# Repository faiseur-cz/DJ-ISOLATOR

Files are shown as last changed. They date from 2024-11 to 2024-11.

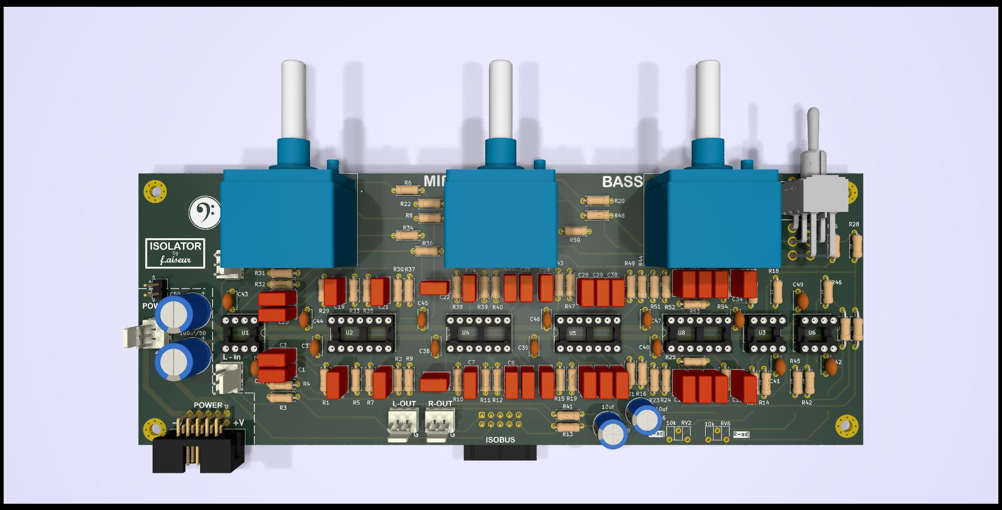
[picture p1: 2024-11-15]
ISOLATOR v002 top.jpg

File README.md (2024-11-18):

# DJ-ISOLATOR
Open-source project of a 3-band "dj isolator"

When i built my first Pathos rotary mixer, a clone of the infamous Bozak CMA-10-2DL, by australian engineer Miles Stevens-aka Fabric Astronaut-, I knew i needed an isolator... so i bought 3 PCBs, from different horizons... i payed a sh+t lot of money for them... and although they worked well, i thought they were not worth it... dont get me wrong! im not criticizing the products, they are all great and amazing, but i felt i could just make it myself, for less money...
Of course, i ended up paying way more... somehow the price of self satisfaction... I learned a lot - and hopefully you will too!

anyway, lets not loose the point!

I basically copied everything from the very generous ESP (Elliott Sound Products) website.. under project numbers :
- Project 09 : 3-Way Linkwitz Riley Crossover
- Project 153 : Frequency 'Isolator' Equaliser
And a lot of other tips from this great knowledge base.

It is a 24dB/oct filter, with frequencies set up at 310Hz and 3k1Hz. You can change those values up to your tastes, for this I can only advise you to fly on ROD ELLIOTT's WEBSITE!!
You can use high quality potentiometers RK27 or more standard ones (i like center detent in those spots).
Either Molex or IDC 10pins connectors are possible for In/Out and power.

https://sound-au.com
https://sound-au.com/project09.htm
https://sound-au.com/project153.htm

https://fabricastronautblog.wordpress.com/2019/06/27/bozak-cma-10-2dl-pt-1-begining/
https://fabricastronautblog.wordpress.com/2016/07/24/pathos-dj-mixer-pt-1/
https://fabricastronautblog.wordpress.com/2016/05/25/dj-isolator-v1-0/

ISOLATOR pcb

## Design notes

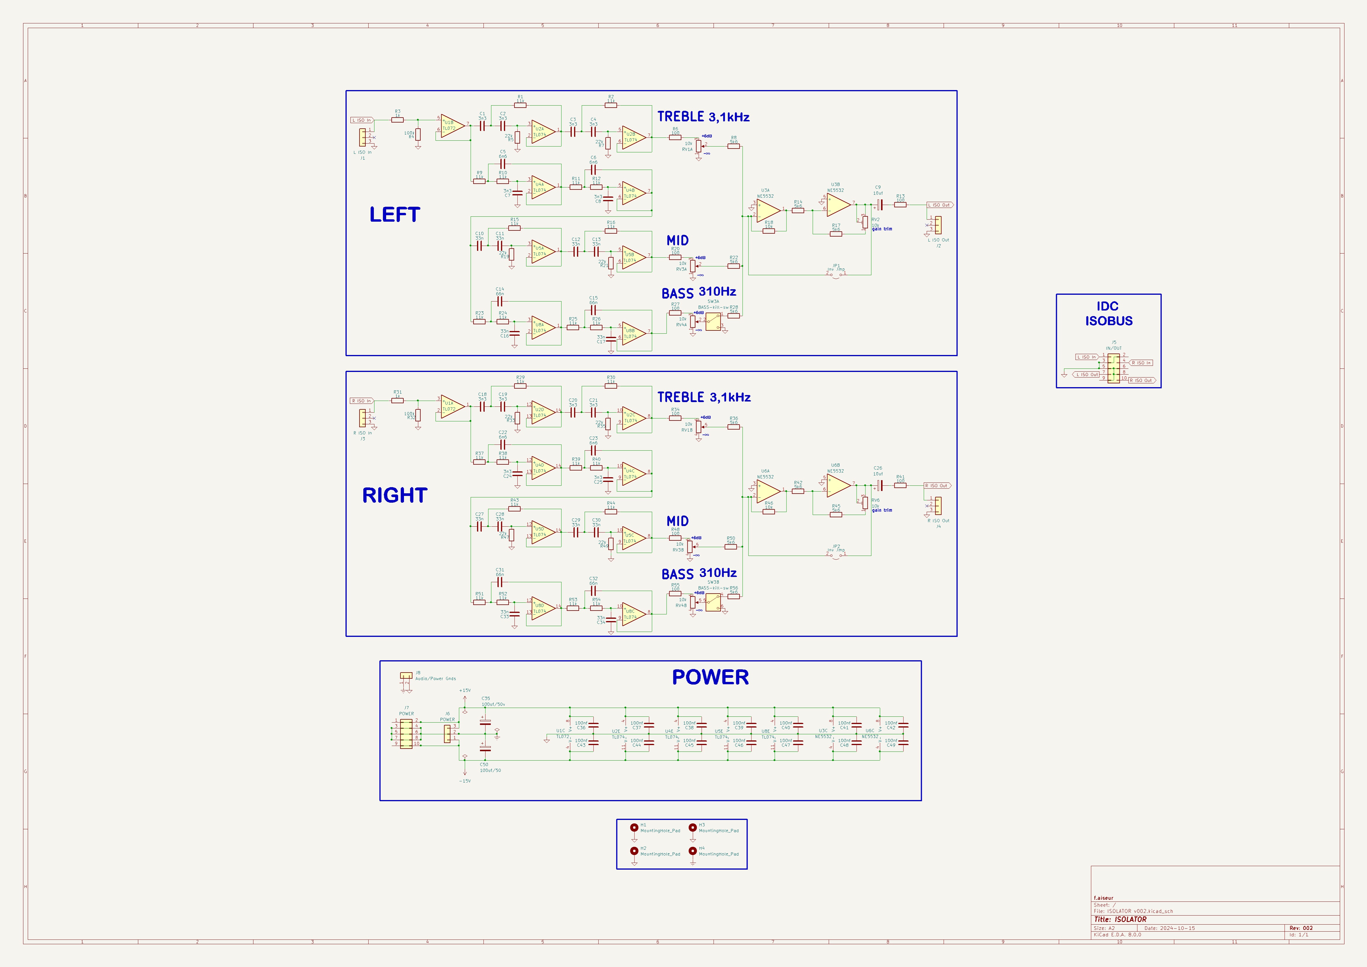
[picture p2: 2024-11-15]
ISOLATOR v002 schematics.jpg

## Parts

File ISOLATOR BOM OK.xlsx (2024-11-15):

Qty | Designator | Value | Footprint | LINK | Price (total)
CAPACITORS
Film
4 | C15,C32,C14,C31 | 66n (68n) | L7.2mm_W3.5mm_P5.00mm_FKS2_FKP2_MKS2_MKP2 | https://www.mouser.fr/ProductDetail/Panasonic/ECQ-E2683JB?qs=9ouE0kzBZ2rJ9WYgSPnN8Q%3D%3D | 1.64 € | https://www.mouser.fr/ProductDetail/505-MKS2.068-50-10 | 2.05 €
12 | C16,C12,C17,C29,C34,C10,C11,C33,C13,C30,C27,C28 | 33n | L7.2mm_W3.5mm_P5.00mm_FKS2_FKP2_MKS2_MKP2 | https://www.mouser.fr/ProductDetail/WIMA/MKS4D023302A00KSSD | 3.34 €
4 | C23,C22,C5,C6 | 6n6 (6n8) | L7.2mm_W3.5mm_P5.00mm_FKS2_FKP2_MKS2_MKP2 | https://www.mouser.fr/ProductDetail/505-MKP2J016801C00KS | 2.38 €
12 | C8,C20,C19,C25,C7,C2,C1,C24,C21,C18,C4,C3 | 3n3 | L7.2mm_W3.5mm_P5.00mm_FKS2_FKP2_MKS2_MKP2 | https://www.mouser.fr/ProductDetail/WIMA/FKS2D013301A00KSSD | 3.90 €
Electro
2 | C9,C26 | 10uf | CP_Radial_D8.0mm_P2.50mm | https://www.mouser.fr/ProductDetail/KYOCERA-AVX/REF0612100M120K?qs=Y0Uzf4wQF3kVQWBNZv6kPQ%3D%3D | 0.52 €
2 | C35, C50 | 100uf/50v | CP_Radial_D10.0mm_P2.50mm | https://www.mouser.fr/ProductDetail/Rubycon/50TXW100MEFC6.3X25?qs=T3oQrply3y%2FfQ2ZfBW7NUQ%3D%3D | 2.02 €
Ceramic
14 | C42,C36,C43,C39,C45,C41,C48,C40,C44,C47,C49, C37,C38,C46 | 100nf | C_Disc_D5.0mm_W2.5mm_P5.00mm | https://www.mouser.fr/ProductDetail/TDK/FK26C0G1H104J?qs=zLBlM7QTTNq9rTkG%2Fo4Low%3D%3D | 4.33 €
CONNECTORS
5 | J1, J2, J3, J4, J6 | L ISO In, R ISO In, … | Molex_KK-254_AE-6410-03A_1x03_P2.54mm_Vertical | https://www.gmelectronic.com/v/1497520/kk254-3pinm-plug-connector-pitch-254mm-1x3pins-straight-to-pcb | 0.25 € | 800-095
1 | J5, J7 | IN/OUT, POWER | IDC-Header_2x05_P2.54mm_Horizontal | https://www.gmelectronic.com/v/1498388/kls-mlw10g-plug-connector-pitch-254mm-2x5pin-straight-to-pcb | 0.42 € | 800-035
JUMPERS
1 | J8 | Aud/Pwr Gnds | PinHeader_1x02_P2.54mm_Vertical | Resistor leg or 0ohm resistor |  | you can insulate them, it doesn’t hurt..
2 | JP1,JP2 | Inv Jmp | R_Axial_DIN0207_L6.3mm_D2.5mm_P10.16mm_Horizontal | Resistor leg or 0ohm resistor |  | you can insulate them, it doesn’t hurt..
RESISTORS
8 | R13,R48,R41,R6,R27,R34, R55,R20 | 100 | DIN0207_L6.3mm_D2.5mm_P7.62mm_Horizontal
10 | R17,R45,R42,R8,R14,R22, R56,R50,R36,R28 | 5k6 | DIN0207_L6.3mm_D2.5mm_P7.62mm_Horizontal
8 | R21,R33,R5,R19,R49,R47, R7,R35 | 22k | DIN0207_L6.3mm_D2.5mm_P7.62mm_Horizontal
2 | R31,R3 | 1k | DIN0207_L6.3mm_D2.5mm_P7.62mm_Horizontal
2 | R4,R32 | 100k | DIN0207_L6.3mm_D2.5mm_P7.62mm_Horizontal
24 | R40,R24,R11,R2,R53,R9, R52,R39,R10,R23,R30,R54,R38,R29,R51,R12,R37, R15,R1,R25,R44,R43,R26,R16 | 11k | R_Axial_DIN0207_L6.3mm_D2.5mm_P7.62mm_Horizontal
2 | R46,R18 | 10k | R_Axial_DIN0207_L6.3mm_D2.5mm_P7.62mm_Horizontal
TRIMMERS / POTENTIOMETERS
2 | RV2,RV6 | 10k | Potentiometer_Piher_PT-6-H_Horizontal | https://www.gmelectronic.com/v/1486444/piher-pt6hk010-carbon-trimmer | 0.96 € | 112-177
3 | RV3,RV1,RV4 | 10k | RK27 // OR // standard dual pot |  | 30.00 € | Ebay,Mouser….
Toggle SWITCH
1 | SW3 | BASS-kill-sw | 100DP1T1B4M7QE | https://www.mouser.fr/ProductDetail/E-Switch/100DP1T1B4M7QE?qs=f57gQzlyLip%2FjylN%252B95kPQ%3D%3D | 4.58 €
ICs
1 | U1 | TL072 | DIP-8_W7.62mm_Socket | https://www.gmelectronic.com/v/1490183/texas-instruments-tl072cp | 0.76 € | 311-013
4 | U5,U2,U8,U4 | TL074 | DIP-14_W7.62mm_Socket | https://www.gmelectronic.com/v/1487648/texas-instruments-tl074cn | 2.87 € | 311-014
2 | U6,U3 | NE5532 | DIP-8_W7.62mm_Socket | https://www.gmelectronic.com/v/1490181/texas-instruments-ne5532p | 1.16 € | https://www.gmelectronic.com/v/1490181/texas-instruments-ne5532p | 1.12 €
TOTAL COST |  |  |  |  | 59.13 € | IF RK27

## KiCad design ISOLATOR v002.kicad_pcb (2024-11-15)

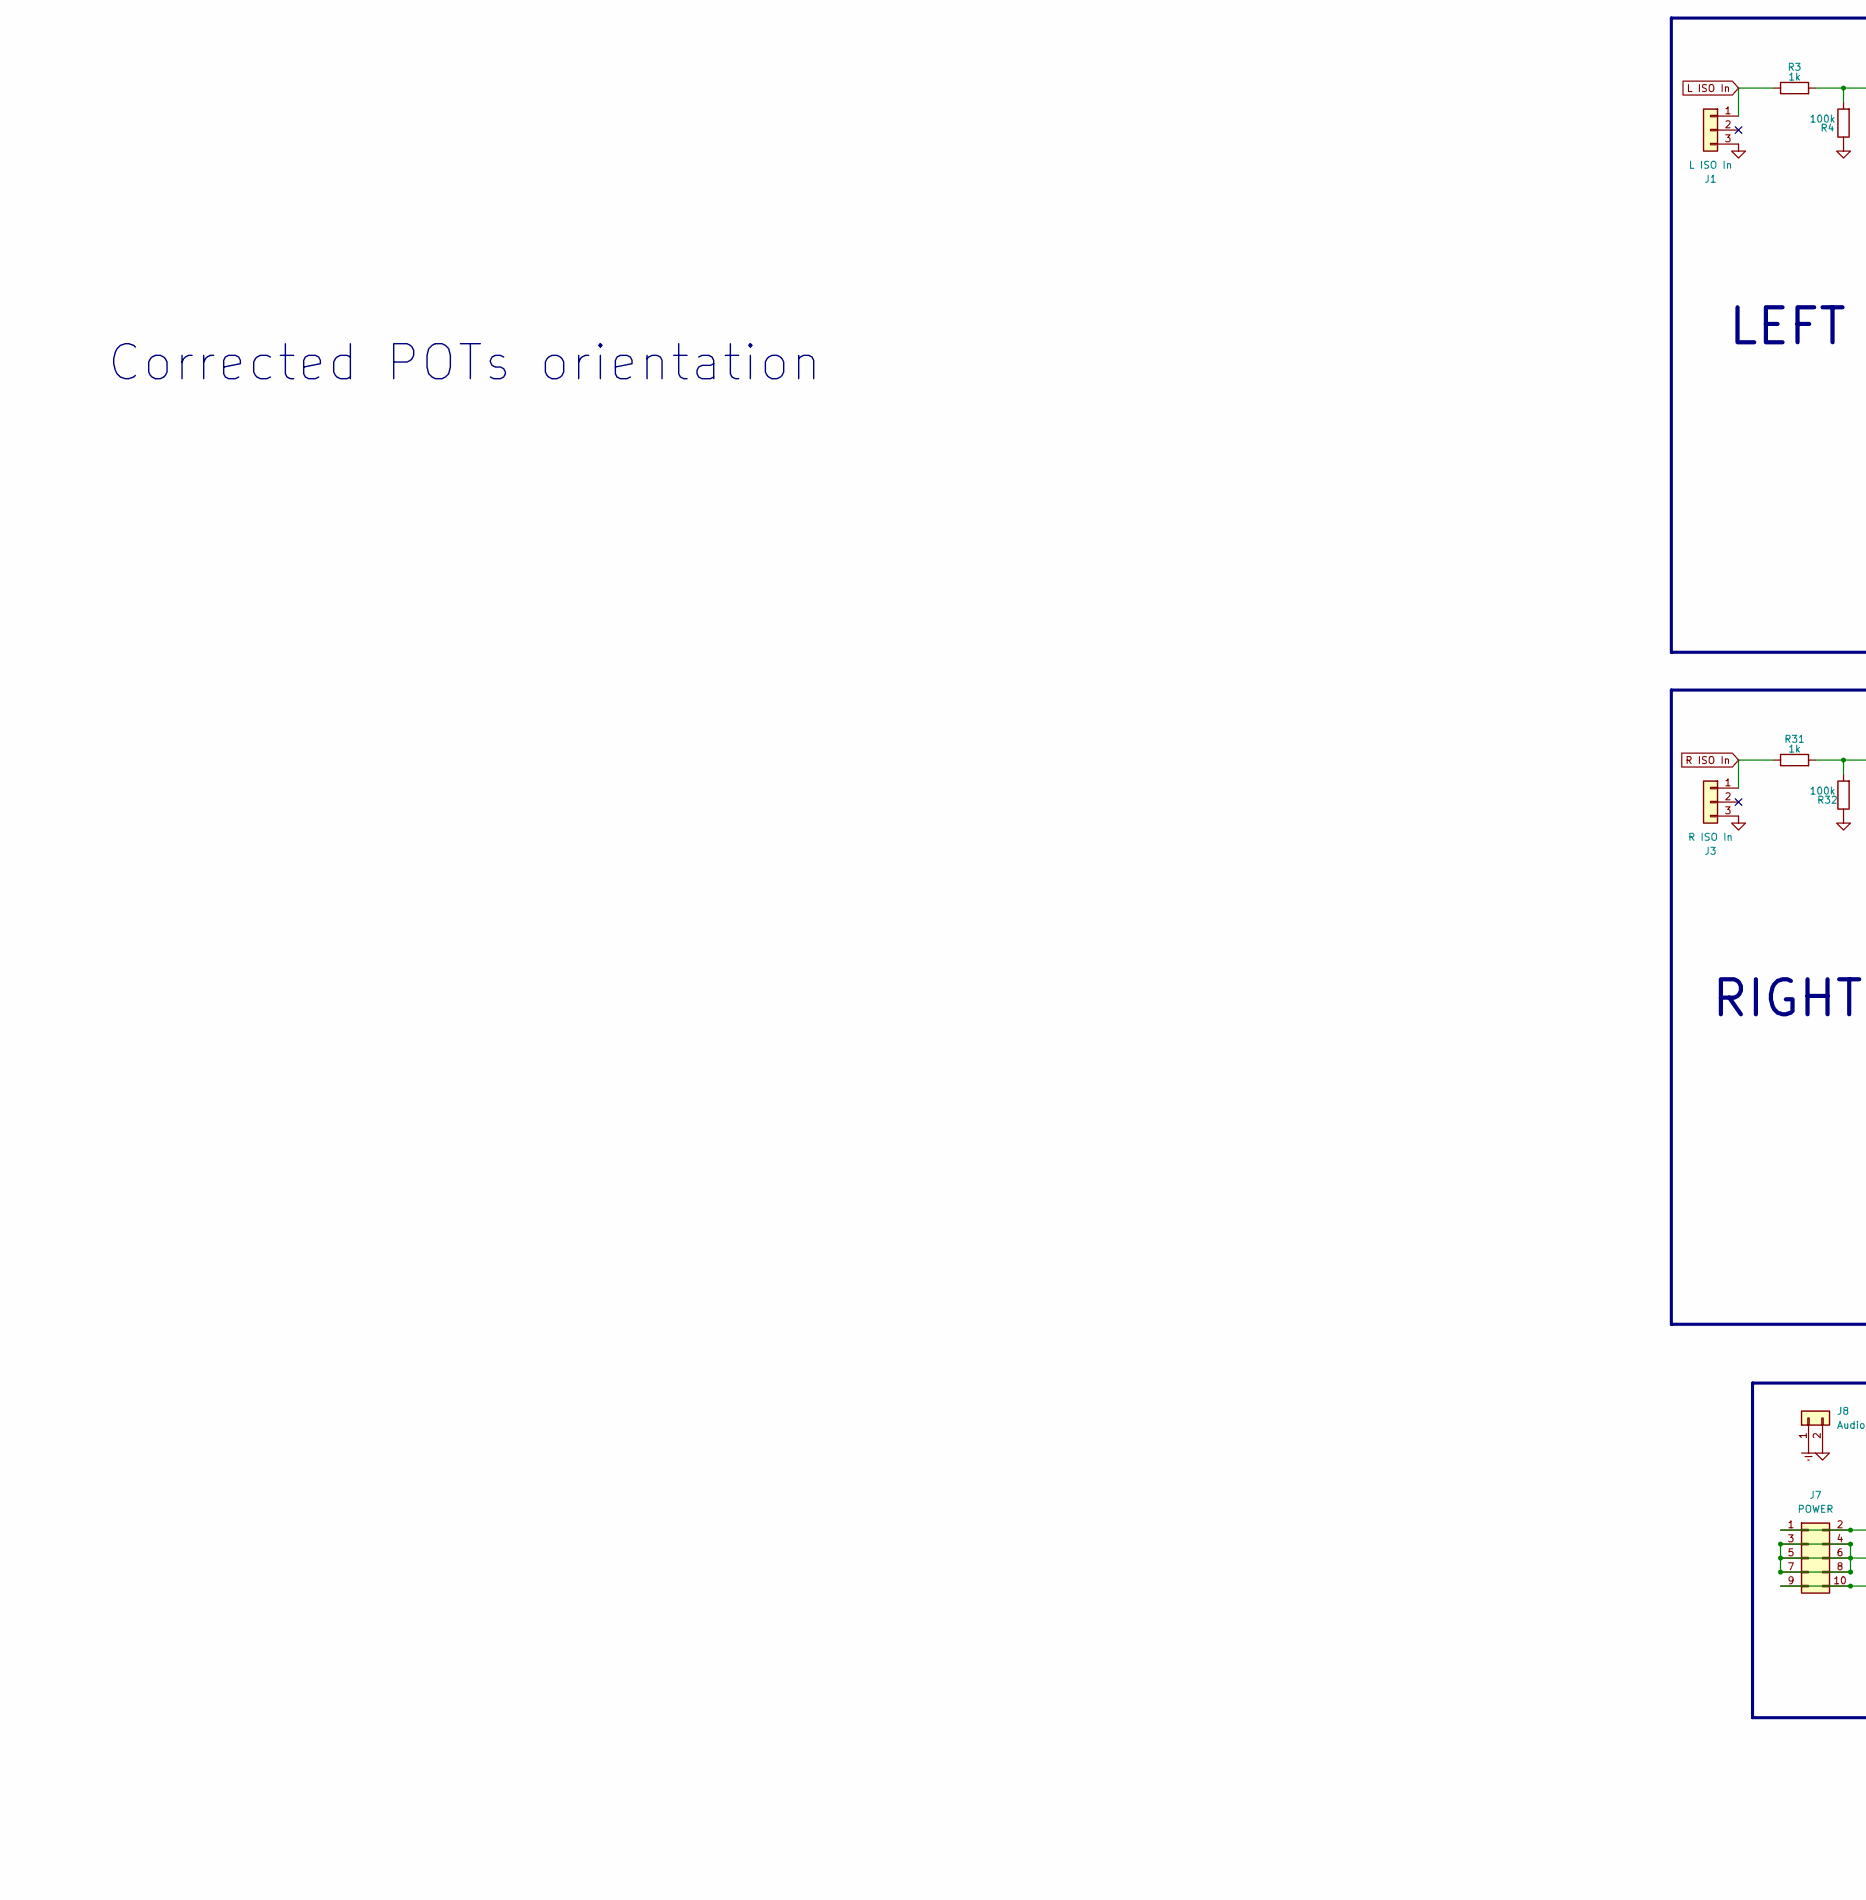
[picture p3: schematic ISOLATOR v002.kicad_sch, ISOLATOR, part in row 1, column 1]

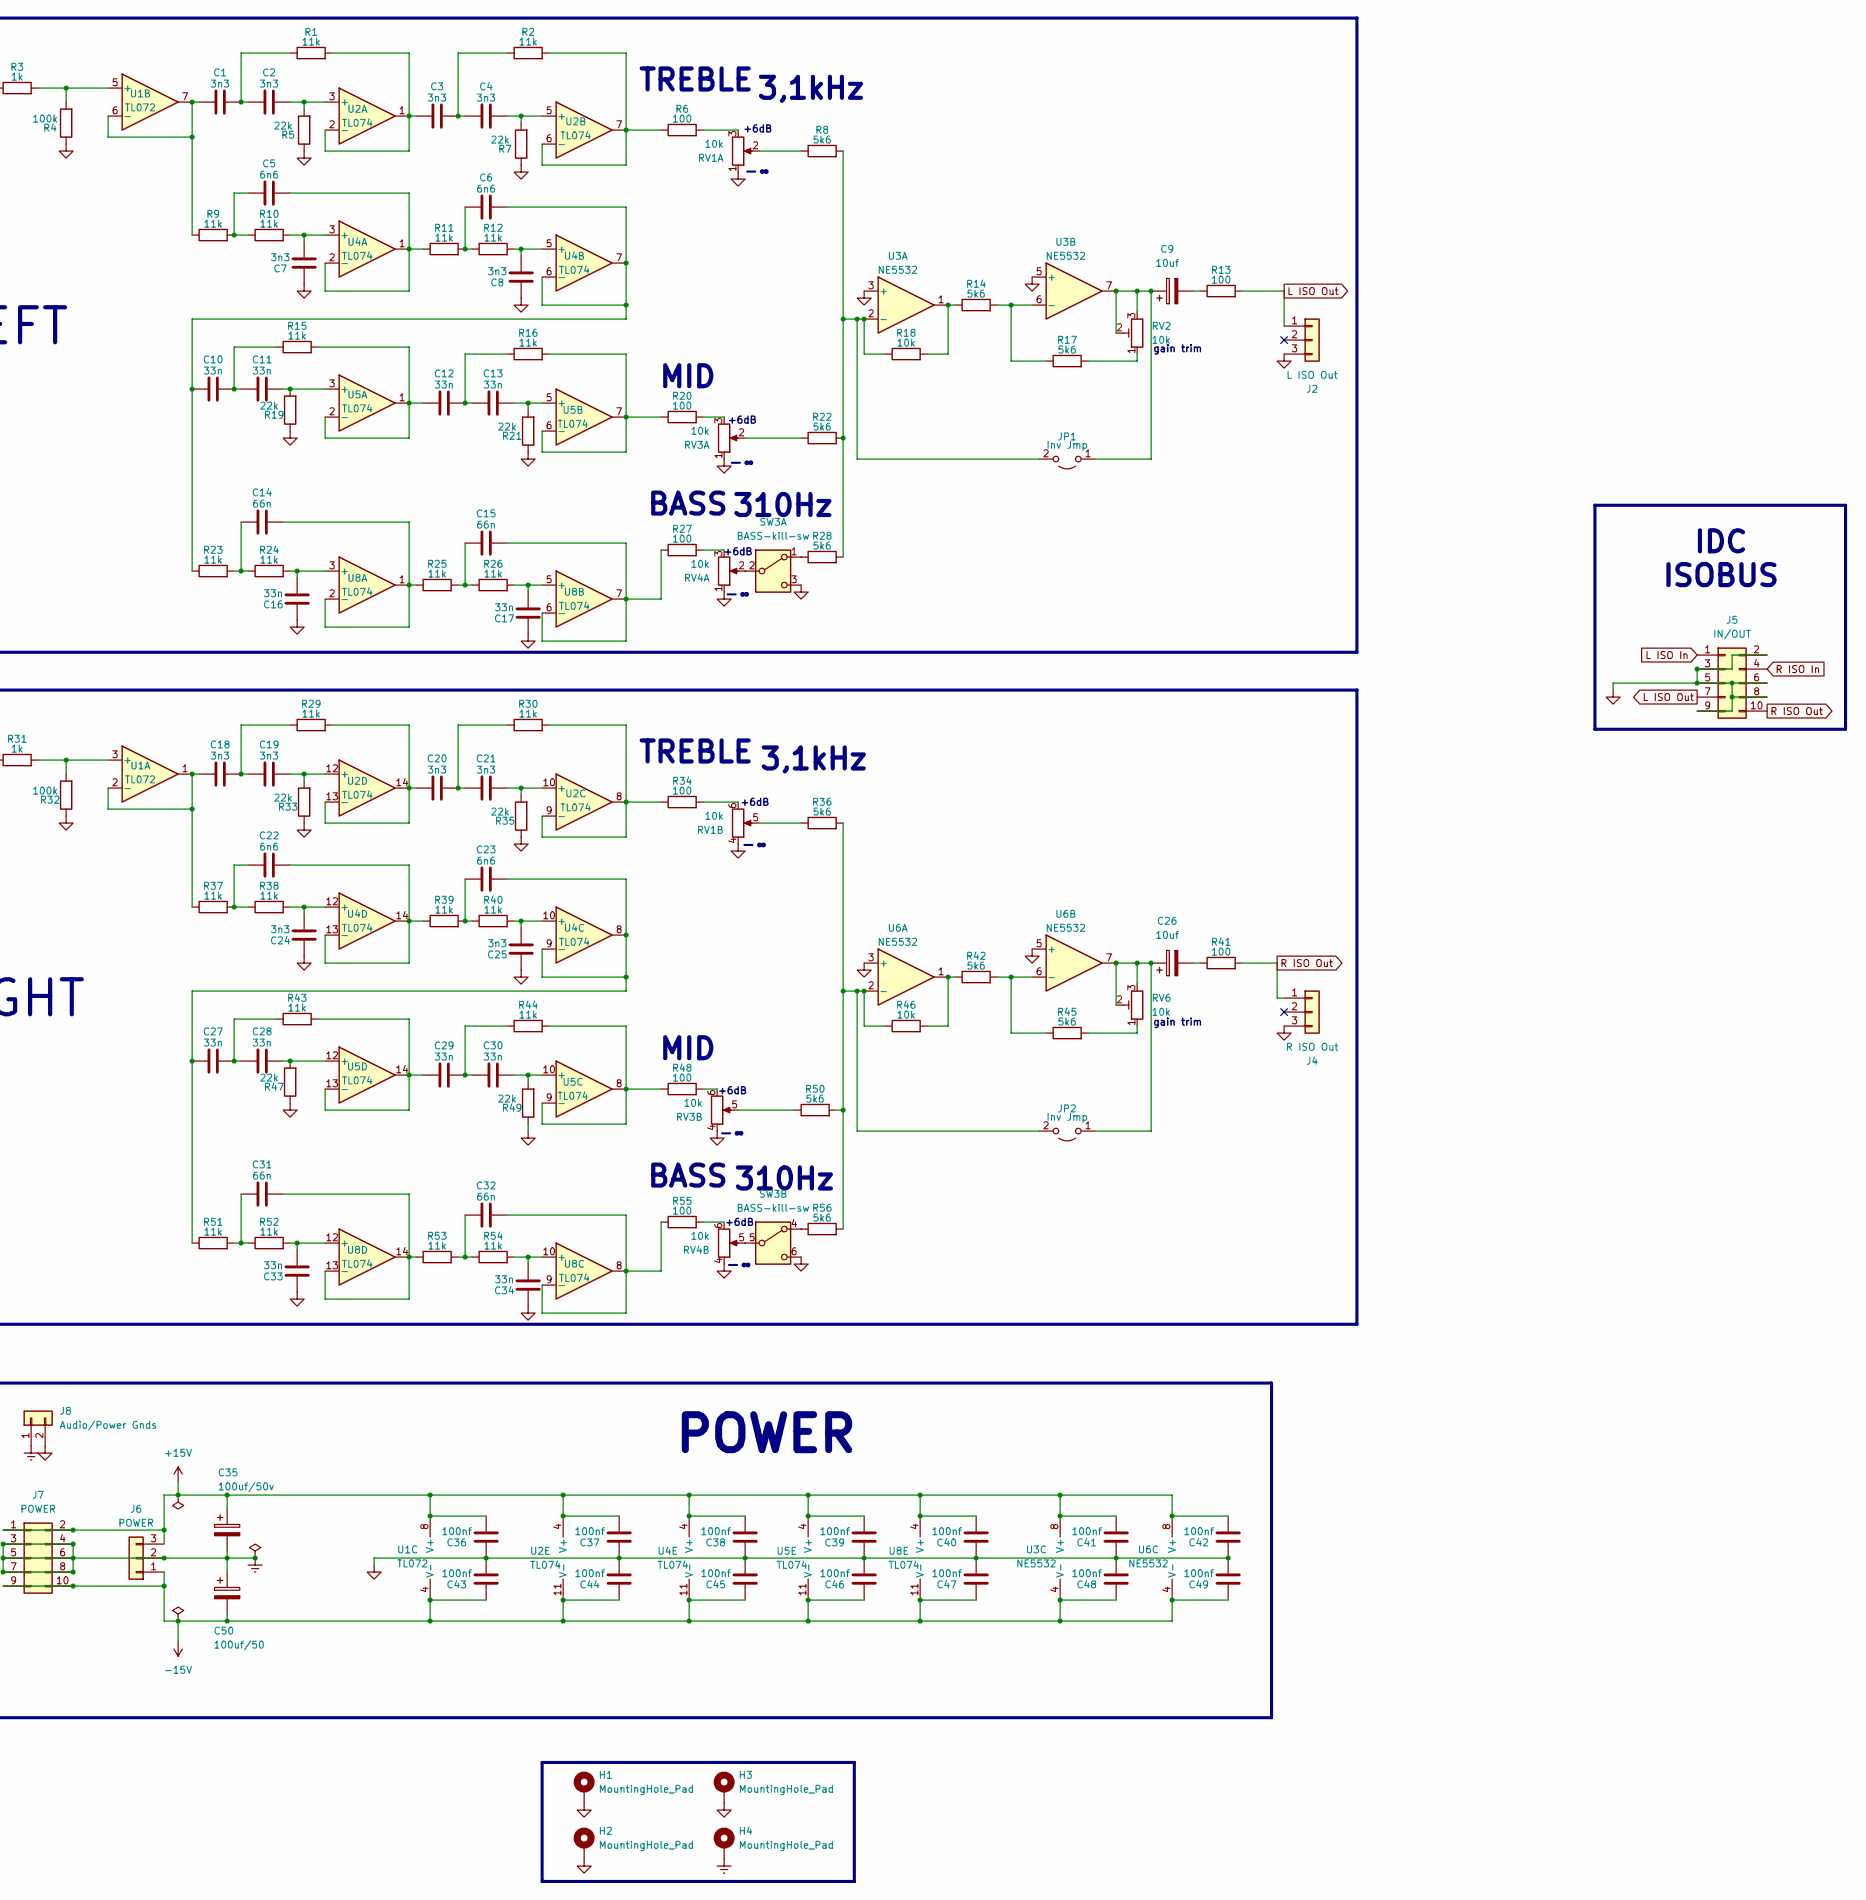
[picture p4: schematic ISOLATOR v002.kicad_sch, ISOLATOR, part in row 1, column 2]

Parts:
C1, C2, C3, C4, C7, C8, C18, C19, C20, C21, C24, C25: 3n3; C_Rect_L7.2mm_W3.5mm_P5.00mm_FKS2_FKP2_MKS2_MKP2
C5, C6, C22, C23: 6n6; C_Rect_L7.2mm_W3.5mm_P5.00mm_FKS2_FKP2_MKS2_MKP2
C9, C26: 10uf; CP_Radial_D8.0mm_P2.50mm
C10, C11, C12, C13, C16, C17, C27, C28, C29, C30, C33, C34: 33n; C_Rect_L7.2mm_W3.5mm_P5.00mm_FKS2_FKP2_MKS2_MKP2
C14, C15, C31, C32: 66n; C_Rect_L7.2mm_W3.5mm_P5.00mm_FKS2_FKP2_MKS2_MKP2
C35: 100uf/50v; CP_Radial_D10.0mm_P2.50mm
C36, C37, C38, C39, C40, C41, C42, C43, C44, C45, C46, C47, C48, C49: 100nf; C_Disc_D5.0mm_W2.5mm_P5.00mm
C50: 100uf/50; CP_Radial_D10.0mm_P2.50mm
H1, H2, H3, H4: MountingHole_Pad; MountingHole_3.2mm_M3_Pad_Via
J1: L ISO In; Molex_KK-254_AE-6410-03A_1x03_P2.54mm_Vertical
J2: L ISO Out; Molex_KK-254_AE-6410-03A_1x03_P2.54mm_Vertical
J3: R ISO In; Molex_KK-254_AE-6410-03A_1x03_P2.54mm_Vertical
J4: R ISO Out; Molex_KK-254_AE-6410-03A_1x03_P2.54mm_Vertical
J5: IN/OUT; IDC-Header_2x05_P2.54mm_Horizontal
J6: POWER; Molex_KK-254_AE-6410-03A_1x03_P2.54mm_Vertical
J7: POWER; IDC-Header_2x05_P2.54mm_Horizontal
J8: Audio/Power Gnds; PinHeader_1x02_P2.54mm_Vertical
JP1, JP2: Inv Jmp; R_Axial_DIN0207_L6.3mm_D2.5mm_P10.16mm_Horizontal
R1, R2, R9, R10, R11, R12, R15, R16, R23, R24, R25, R26, R29, R30, R37, R38, R39, R40, R43, R44, R51, R52, R53, R54: 11k; R_Axial_DIN0207_L6.3mm_D2.5mm_P7.62mm_Horizontal
R3, R31: 1k; R_Axial_DIN0207_L6.3mm_D2.5mm_P7.62mm_Horizontal
R4, R32: 100k; R_Axial_DIN0207_L6.3mm_D2.5mm_P7.62mm_Horizontal
R5, R7, R19, R21, R33, R35, R47, R49: 22k; R_Axial_DIN0207_L6.3mm_D2.5mm_P7.62mm_Horizontal
R6, R13, R20, R27, R34, R41, R48, R55: 100; R_Axial_DIN0207_L6.3mm_D2.5mm_P7.62mm_Horizontal
R8, R14, R17, R22, R28, R36, R42, R45, R50, R56: 5k6; R_Axial_DIN0207_L6.3mm_D2.5mm_P7.62mm_Horizontal
R18, R46: 10k; R_Axial_DIN0207_L6.3mm_D2.5mm_P7.62mm_Horizontal
RV1, RV3, RV4: 10k; RK27 + standard dual pot
RV2, RV6: 10k; Potentiometer_Piher_PT-6-H_Horizontal
SW3: BASS-kill-sw; 100DP1T1B4M7QE
U1: TL072; DIP-8_W7.62mm_Socket
U2, U4, U5, U8: TL074; DIP-14_W7.62mm_Socket
U3, U6: NE5532; DIP-8_W7.62mm_Socket

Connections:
+15V: C35.1, C36.2, C37.2, C38.2, C39.2, C40.2, C41.2, C42.2, J6.3, J7.1, J7.2, U1.8 (V+), U2.4 (V+), U3.8 (V+), U4.4 (V+), U5.4 (V+), U6.8 (V+), U8.4 (V+)
-15V: C43.1, C44.1, C45.1, C46.1, C47.1, C48.1, C49.1, C50.2, J6.1, J7.9, J7.10, U1.4 (V-), U2.11 (V-), U3.4 (V-), U4.11 (V-), U5.11 (V-), U6.4 (V-), U8.11 (V-)
GND: C7.1, C8.1, C16.1, C17.1, C24.1, C25.1, C33.1, C34.1, C36.1, C37.1, C38.1, C39.1, C40.1, C41.1, C42.1, C43.2, C44.2, C45.2, C46.2, C47.2, C48.2, C49.2, H1.1, H2.1, H3.1, J1.3, J2.3, J3.3, J4.3, J5.2, J5.3, J5.5, J5.6, J5.8, J5.9, J8.2, R4.1, R5.1, R7.1, R19.1, R21.1, R32.1, R33.1, R35.1, R47.1, R49.1, RV1.1, RV1.4, RV3.1, RV3.4, RV4.1, RV4.4, SW3.3 (C), SW3.6 (C), U3.3 (+), U3.5 (+), U6.3 (+), U6.5 (+)
GNDREF: C35.2, C50.1, H4.1, J6.2, J7.3, J7.4, J7.5, J7.6, J7.7, J7.8, J8.1
L ISO In: J1.1, J5.1, R3.1
L ISO Out: J2.1, J5.7, R13.2
unnamed: C1.2, C2.1, R1.1
unnamed: C3.2, C4.1, R2.1
unnamed: C5.1, R9.2, R10.1
unnamed: C6.1, R11.2, R12.1
unnamed: C9.2, R13.1
unnamed: C10.2, C11.1, R15.1
unnamed: C12.2, C13.1, R16.1
unnamed: C14.1, R23.2, R24.1
unnamed: C15.1, R25.2, R26.1
unnamed: C18.2, C19.1, R29.1
unnamed: C20.2, C21.1, R30.1
unnamed: C22.1, R37.2, R38.1
unnamed: C23.1, R39.2, R40.1
unnamed: C26.2, R41.1
unnamed: C27.2, C28.1, R43.1
unnamed: C29.2, C30.1, R44.1
unnamed: C31.1, R51.2, R52.1
unnamed: C32.1, R53.2, R54.1
unnamed: C9.1, JP1.1 (A), RV2.2, RV2.3, U3.7
unnamed: JP1.2 (B), R8.2, R18.1, R22.2, R28.2, U3.2 (-)
unnamed: C26.1, JP2.1 (A), RV6.2, RV6.3, U6.7
unnamed: JP2.2 (B), R36.2, R46.1, R50.2, R56.2, U6.2 (-)
unnamed: R6.2, RV1.3
unnamed: R8.1, RV1.2
unnamed: R14.1, R18.2, U3.1
unnamed: R17.2, RV2.1
unnamed: R20.2, RV3.3
unnamed: R22.1, RV3.2
unnamed: R27.2, RV4.3
unnamed: R34.2, RV1.6
unnamed: R36.1, RV1.5
unnamed: R42.1, R46.2, U6.1
unnamed: R45.2, RV6.1
unnamed: R48.2, RV3.6
unnamed: R50.1, RV3.5
unnamed: R55.2, RV4.6
unnamed: R28.1, SW3.1 (A)
unnamed: RV4.2, SW3.2 (B)
unnamed: R56.1, SW3.4 (A)
unnamed: RV4.5, SW3.5 (B)
unnamed: R31.2, R32.2, U1.3 (+)
unnamed: C18.1, R37.1, U1.1, U1.2 (-)
unnamed: R3.2, R4.2, U1.5 (+)
unnamed: C1.1, R9.1, U1.6 (-), U1.7
unnamed: C2.2, R5.2, U2.3 (+)
unnamed: C3.1, R1.2, U2.1, U2.2 (-)
unnamed: C4.2, R7.2, U2.5 (+)
unnamed: R2.2, R6.1, U2.6 (-), U2.7
unnamed: C21.2, R35.2, U2.10 (+)
unnamed: R30.2, R34.1, U2.8, U2.9 (-)
unnamed: C19.2, R33.2, U2.12 (+)
unnamed: C20.1, R29.2, U2.13 (-), U2.14
unnamed: R14.2, R17.1, U3.6 (-)
unnamed: C7.2, R10.2, U4.3 (+)
unnamed: C5.2, R11.1, U4.1, U4.2 (-)
unnamed: C8.2, R12.2, U4.5 (+)
unnamed: C6.2, C10.1, R23.1, U4.6 (-), U4.7
unnamed: C25.2, R40.2, U4.10 (+)
unnamed: C23.2, C27.1, R51.1, U4.8, U4.9 (-)
unnamed: C24.2, R38.2, U4.12 (+)
unnamed: C22.2, R39.1, U4.13 (-), U4.14
unnamed: C11.2, R19.2, U5.3 (+)
unnamed: C12.1, R15.2, U5.1, U5.2 (-)
unnamed: C13.2, R21.2, U5.5 (+)
unnamed: R16.2, R20.1, U5.6 (-), U5.7
unnamed: C30.2, R49.2, U5.10 (+)
unnamed: R44.2, R48.1, U5.8, U5.9 (-)
unnamed: C28.2, R47.2, U5.12 (+)
unnamed: C29.1, R43.2, U5.13 (-), U5.14
unnamed: R42.2, R45.1, U6.6 (-)
unnamed: C16.2, R24.2, U8.3 (+)
unnamed: C14.2, R25.1, U8.1, U8.2 (-)
unnamed: C17.2, R26.2, U8.5 (+)
unnamed: C15.2, R27.1, U8.6 (-), U8.7
unnamed: C34.2, R54.2, U8.10 (+)
unnamed: C32.2, R55.1, U8.8, U8.9 (-)
unnamed: C33.2, R52.2, U8.12 (+)
unnamed: C31.2, R53.1, U8.13 (-), U8.14
R ISO In: J3.1, J5.4, R31.1
R ISO Out: J4.1, J5.10, R41.2

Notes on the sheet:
BASS
LEFT
+6dB
gain trim
MID
TREBLE
IDC ISOBUS
310Hz
RIGHT
Corrected POTs orientation
3,1kHz
POWER

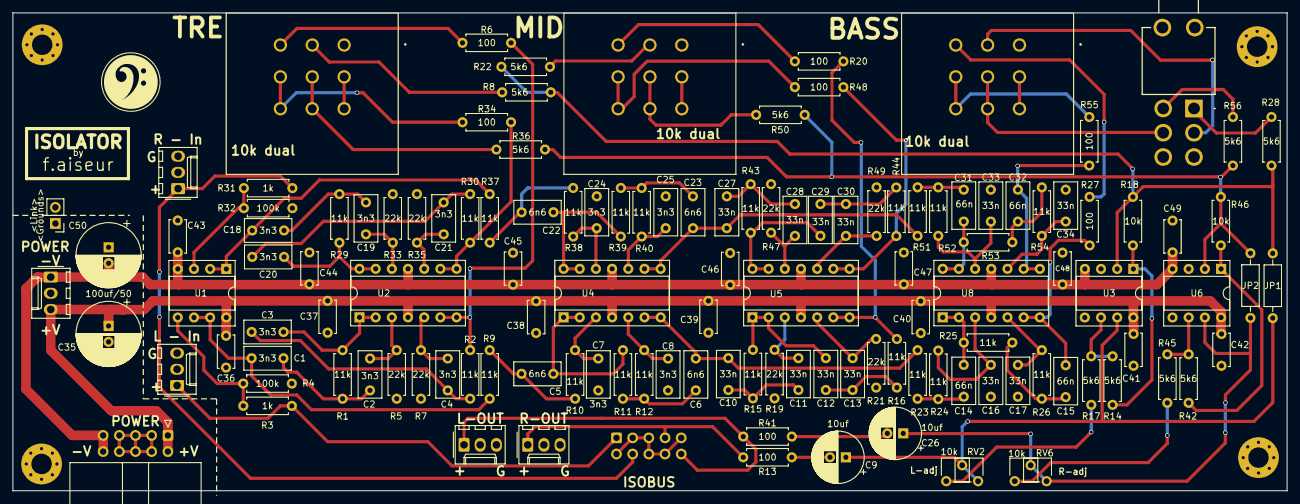
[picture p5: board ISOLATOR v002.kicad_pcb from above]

Board: 2 copper layers, 200.0 x 75.0 mm, 133 parts (1 on the bottom side), 86 nets.
